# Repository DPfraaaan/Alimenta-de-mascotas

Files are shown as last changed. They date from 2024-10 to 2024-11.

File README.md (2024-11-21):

# Alimentador-de-mascotas

El proyecto consiste en un alimentador automático de mascotas que consta de un tanque de comida y un plato que incluye una balanza para medir el peso de la comida que hay en él. Este dispositivo rellenará automáticamente el plato cuando esté vacío.

### Funcionamiento Planteado: 
Con un botón se permitirá cambiar la frecuencia con la que se rellena el plato, con intervalos de 4 horas.
El alimentador contará con una pantalla que mostrará información como la cantidad de comida en gramos en el plato y el tiempo restante para el próximo rellenado, en caso de que el animal haya consumido toda la comida del plato actual. Por último, incluirá un sensor ultrasónico que medirá el nivel del tanque. Si está lleno, se encenderá un LED verde y si está bajo, un LED rojo. Cuando el nivel esté muy bajo, se activará un buzzer como alarma.

### Componentes:
* Sensor ultrasonido (Hc-sr04)
* Leds (Verde ;Rojo)
* Buzzer 
* Servo (sg-90)
* ESP-32
* Celda de carga (1kg) Hx711
* Pantalla LCD 16x2 I2C
* 1 Botón genéricO

#### Después se agrego:

* LDR

### Comunicación entre módulos y MCU
* i2c ( pantalla LCD, Servo, sensor de ultrasonido ) 
* 2 pines (Clock y Data), de forma serial muy similar a I2C (celda de carga)
* PWM (servomotor ( como tal no es un sistema ) )

## Diagrama de conexión



## Actualizaión:
Un botón fue eliminado debido a que no era relevante
* Se opto por solo un botón que permite cambiar los intervalos de relleno del plato de comida de a 4hs cada intervalo.

### Actualización V3:
Debido a distintos problemas.
* Se quitó celda de carga.
* Se agregó LDR.
* Se cambió el planteamento del funcionamiento.
  
¡¡Más info abajo del README!!

## Objetivos
* Lograr el funcionamiento propuesto en un inicio haciendo un dispositivo funcional y práctico

## Alcances
* No se completó en sí como se planteo inicialmente el proyecto, pero gracias a alternativas conseguimos un comedero automatico sin el uso de la báscula

## Problemas encontrados durante el proceso:
* Es importante tener en cuenta que el ESP trabaja con un nivel lógico de voltajes de 3,3 V, entonces la algunos de sensores u actuadores podrían no funcionar con los niveles lógicos del ESP por lo que lo ideal es implementar un logic level shifter de 5v <-- (nivel lógico de la mayoría de sensores implementados) a 3,3 V. (al final todos nuestros actuadores, sensores y LCD permitían su correcto funcionamiento con 3,3 V por lo que no se implementó).
* En nuestro caso la configuración de la resistencia de carga fue muy complicada y no pudimos conseguir el funcionamiento de esta; por esto es que decidimos hacer una versión del alimentador sin esta.

## Ideas para una futrura implementación
* Lograr el funcionamiento de la báscula para cumplir con la idea inicial. (o buscar alternativa a esta).
* Comunicación Wifi o bluethoot o un servidor para aumentar las funcionalidades
* Mejorar el diseño del dispositivo, (agregar más piezas impresas en 3D).

## Cómo funciona nuestra última versión sin báscula

Básicamente cuenta con un LDR que cuando detecta mucha luz (que esta de día), llena el recipiente de comida del animal, esto lo hace una vez en el día. Cuando es de noche o hay poca luz hablita la lectura del tanque, cuando está en niveles de comida adecuados prende un led verde, intermitente; cuando esta en niveles críticos prede un led rojo y un buzer intermitente. El botón se mantuvo este permite selecionar entre perro Grande (G), Mediano (M), Chico (C). Como no tenemos una báscula para medir los niveles de comida esto lo que hace es cambiar el tiempo de apertura del servo. Más tiempo, más comida (ej perro grande), menos tiempo menos comida (perro chico). La informacón de tipo de perro está mostrada en el LCD.

### ¡¡Información de hadware y software (LDR) se encuentran en el github!!

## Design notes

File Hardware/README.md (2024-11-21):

# Documentación
Aquí se encuentra información sobre los distintos componentes del proyecto, la función que cumplen, algunas características importantes de cada uno y el enlace a las hojas de datos (datasheets) de cada componente.
## Descripción:
### ESP-32


 El ESP-32 es un microcontrolador potente y versátil que cuenta con conectividad Wi-Fi y Bluetooth. Es ideal para proyectos de Internet de las Cosas (IoT) y ofrece múltiples pines de entrada/salida, así como capacidades de procesamiento para ejecutar diversas aplicaciones.
 
------------------

### Sensor Ultrasonido (HC-SR04)
Descripción de la imagen

El HC-SR04 es un sensor de distancia que utiliza ondas ultrasónicas para medir la distancia a un objeto. Emite un pulso de sonido a 40 kHz y mide el tiempo que tarda en regresar el eco. Es útil en aplicaciones como la medición de distancias y la detección de obstáculos.

------------------

### LEDs (Verde, Amarillo, Rojo)
Descripción de la imagen

Los LEDs (diodos emisores de luz) son componentes electrónicos que emiten luz cuando se les aplica corriente. En este caso, los LEDs de colores (verde, amarillo y rojo) se pueden usar para indicar estados diferentes en un sistema, como el funcionamiento normal (verde), advertencias (amarillo) o errores (rojo).

------------------

### Buzzer
Descripción de la imagen

El buzzer es un dispositivo que produce sonido al recibir una señal eléctrica. Puede ser un buzzer pasivo (requiere una señal de audio) o activo (produce un tono fijo). Se utiliza en alarmas, notificaciones y sistemas de alerta.

------------------

### Servo (SG-90)
Descripción de la imagen

El SG-90 es un servomotor de bajo costo que permite un control preciso de la posición angular. Tiene un rango de movimiento de aproximadamente 180 grados y se utiliza comúnmente en aplicaciones de robótica y automatización, como el control de brazos robóticos o mecanismos de dirección.

------------------

### Celda de Carga (1 kg) con HX711
Descripción de la imagen
Descripción de la imagen

La celda de carga es un sensor que mide el peso aplicando una fuerza. En este caso, tiene una capacidad de 1 kg. El HX711 es un amplificador de señal diseñado para leer la salida de la celda de carga, permitiendo medir con precisión el peso en aplicaciones de pesaje y balanzas.

------------------

### Pantalla LCD 16x2 I2C
Descripción de la imagen

Esta pantalla LCD tiene 16 columnas y 2 filas, y utiliza la interfaz I2C para comunicarse con otros dispositivos, lo que simplifica el cableado y la programación. Es ideal para mostrar información, como datos del sensor o mensajes al usuario, en proyectos electrónicos.

------------------

## Si usa LDR
### LDR
images

LDR de 40 KOHM
* Si se desea se puede confiugurar un PULL UP desede las mismas configuraciones del ESP.
* En este caso se utilizo un PULL UP físico.

### Diagrama Pull UP (RPU 10 KOHM)

Captura de pantalla 2024-11-21 201753

## Aviso

#### ¡Se pueden usar los pines que quedan libres al no usar la báscula, quedando 1 sin uso!
EJ:
  
Captura de pantalla 2024-11-21 202111

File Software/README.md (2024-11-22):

# Bibliografía

### Servo 
https://www.youtube.com/watch?v=jJQG936B6uM 

### Hx-711 ( celda de carga )  
https://github.com/akshayvernekar/HX711_IDF/tree/master

## Diagrama de flujo bascula

```mermaid
flowchart TD
    %% Main initialization
    A[Start] --> B[Initialize I2C & LCD]
    B --> C[General Config\n- GPIO Setup\n- Servo PWM Setup]
    C --> D[Configure Hardware Timers\n- Ultrasonic Timer\n- Servo Timers]
    D --> E[Initialize Ultrasonic Sensor]
    
    %% Task Creation
    E --> F[Create FreeRTOS Tasks]
    
    %% Core 0 Tasks
    F --> G[Core 0]
    G --> H[Button Task]
    
    %% Core 1 Tasks
    F --> I[Core 1]
    I --> J[LCD Update Task]
    
    %% Monitor Task (Any Core)
    F --> K[Any Core]
    K --> L[Monitor Task]
    
    %% Button Task Flow
    H --> M{Button\nPressed?}
    M -- Yes --> N[Increment Timer\nby 2 Hours]
    N --> O{Hours >= 24?}
    O -- Yes --> P[Reset Hours to 0]
    O -- No --> M
    P --> M
    
    %% Timer Callback Flow
    Q[Hardware Timer\nCallback] --> R[Increment Minutes]
    R --> S{Minutes >=\nSet Hours?}
    S -- Yes --> T[Check Distance]
    
    %% Distance and Weight Check
    T --> U{Distance\n> 100cm?}
    U -- Yes --> V[Red LED Blink\nShow 'Falta comida']
    U -- No --> W{50cm < Distance\n<= 100cm?}
    W -- Yes --> X[Green LED On\nShow 'Comida ok']
    W -- No --> Y[LEDs Off]
    
    %% Weight Check and Servo Control
    V & X & Y --> Z[Check Weight]
    Z --> AA{Weight\n> 1.5kg?}
    AA -- Yes --> AB[Show 'Hay comida']
    AA -- No --> AC[Move Servo 90°]
    AC --> AD[Wait 500ms]
    AD --> AE[Move Servo 0°]
    
    %% LCD Update Task Flow
    J --> AF{Update\nNeeded?}
    AF -- Yes --> AG[Clear LCD]
    AG --> AH[Show Status]
    AH --> AI[Show Remaining Time]
    AI --> AJ[Reset Update Flag]
    AJ --> AF
    AF -- No --> J
    
    %% Monitor Task Flow
    L --> AK[Check Stack Usage]
    AK --> AL[Print Stack Info]
    AL --> L
    
    %% Styling
    classDef core0 fill:#FFB6C1,stroke:#333,stroke-width:2px
    classDef core1 fill:#90EE90,stroke:#333,stroke-width:2px
    classDef anyCore fill:#87CEEB,stroke:#333,stroke-width:2px
    classDef hardware fill:#FFD700,stroke:#333,stroke-width:2px
    classDef init fill:#DDA0DD,stroke:#333,stroke-width:2px
    
    class A,B,C,D,E,F init
    class G,H,M,N,O,P core0
    class I,J,AF,AG,AH,AI,AJ core1
    class K,L,AK,AL anyCore
    class Q,R,S,T,U,V,W,X,Y,Z,AA,AB,AC,AD,AE hardware
```

## Diagrama de flujo LDR
```mermaid
flowchart TD
    %% Style definitions
    classDef start fill:#4CAF50,stroke:#45a049,color:white
    classDef init fill:#2196F3,stroke:#1976D2,color:white
    classDef process fill:#90CAF9,stroke:#64B5F6,color:black
    classDef decision fill:#FFA726,stroke:#FB8C00,color:black
    classDef alert fill:#EF5350,stroke:#E53935,color:white
    classDef success fill:#66BB6A,stroke:#4CAF50,color:white
    classDef servo fill:#AB47BC,stroke:#8E24AA,color:white
    classDef return fill:#78909C,stroke:#607D8B,color:white

    A[Start] --> B[Initialize Hardware]
    B --> C[Display 'Alimentador' on LCD]
    C --> D{Main}
    
    D --> E[Read Button State]
    E --> F{Button Pressed?}
    F -->|Yes| G[Increment Pet Size]
    G --> H[Update LCD with Size]
    H --> I{5 seconds passed?}
    I -->|Yes| J[Display 'seleccionado']
    I -->|No| D
    F -->|No| K[Check LDR Value]
    
    K --> L{Is it Night?<br/>LDR > threshold}
    L -->|Yes| M[Check Food Level<br/>with Ultrasonic]
    M --> N{Distance > Max_cm?}
    N -->|Yes| O[Blink Red LED<br/>Sound Buzzer]
    N -->|No| P{Min_cm < Distance < Max_cm?}
    P -->|Yes| Q[Blink Green LED]
    
    L -->|No| R{LDR < 600 AND<br/>servobreaker true?}
    R -->|Yes| S[Open Servo 90°]
    S --> T{Check Pet Size}
    T -->|Large| U[Wait 2s]
    T -->|Medium| V[Wait 1s]
    T -->|Small| W[Wait 0.5s]
    U --> X[Close Servo 0°]
    V --> X
    W --> X
    X --> Y[Set servobreaker false]
    
    O --> D
    Q --> D
    Y --> D
    P -->|No| D
    R -->|No| D

    %% Apply styles
    class A start
    class B,C init
    class E,G,H,J,K,M process
    class F,I,L,N,P,R,T decision
    class O alert
    class Q success
    class S,U,V,W,X,Y servo
    class D return
```

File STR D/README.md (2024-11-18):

## Programa Utilizado
Se utilizo Tinkercad como programa de diseño en 3D

Logo-tinkercad-wordmark svg

## ÚTIL
Ademas de las piezas diseñadas en 3D para el tanque se utilizó un bidón de 5 lts, para el alimentador se utlizó un bowl de comida de gato universal

unnamed

(En la imágen se puede observar una boquilla que se diseñó para ayudar al servo en su tarea como valvula de apertura y cierre)

## Metodos de unión
* Cinta doble faz
* Silicona

## Case; placa y componentes principales.

Captura

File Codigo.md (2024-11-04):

## Codigo para el esp32

## bibliografia
https://www.youtube.com/watch?v=jJQG936B6uM
https://www.youtube.com/watch?v=OKbQIeM_1Bs
https://github.com/hardrive9000/PetFeeder/blob/master/Code/main/main.c

https://github.com/UncleRus/esp-idf-lib/tree/master/docs  (este para hx711)

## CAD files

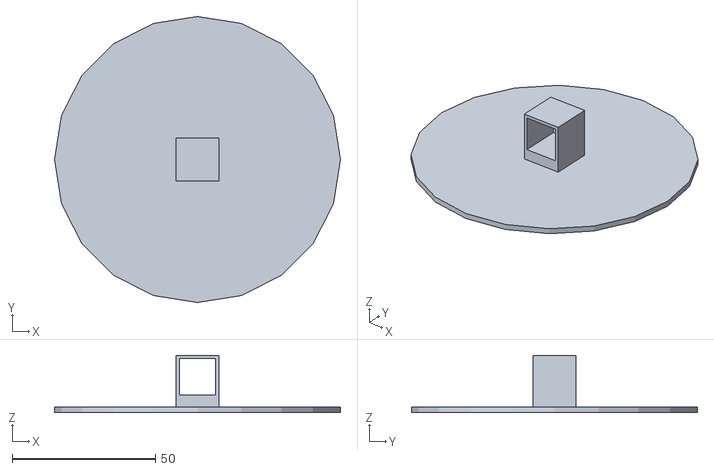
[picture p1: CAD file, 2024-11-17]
STR D/STLS/Soporte bowl.stl
100.0 x 100.0 x 20.0

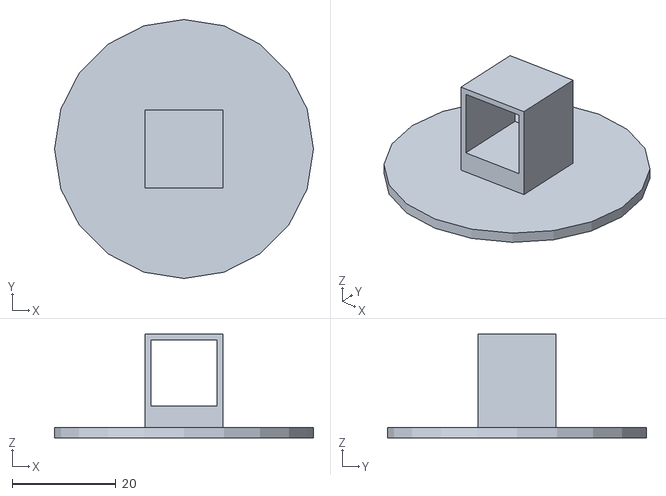
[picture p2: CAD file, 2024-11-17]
STR D/STLS/Soporte sensor Bowl.stl
50.0 x 50.0 x 20.0

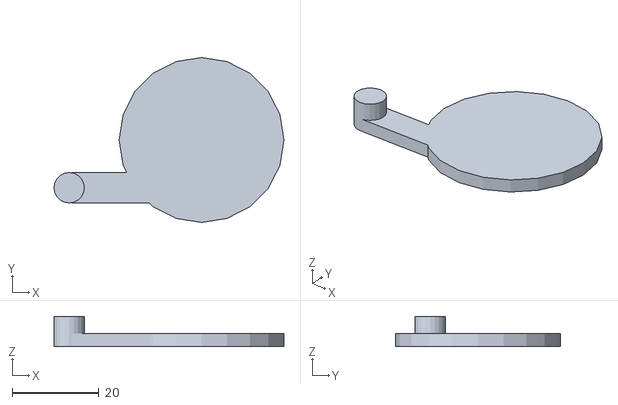
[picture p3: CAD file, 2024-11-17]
STR D/STLS/Brazo servo.stl
53.0 x 38.0 x 7.00

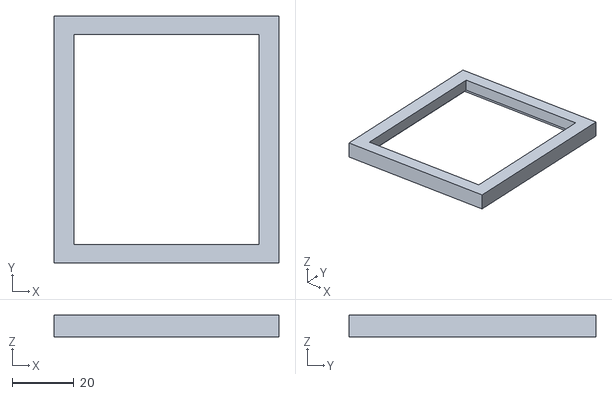
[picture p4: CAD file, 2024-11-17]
STR D/STLS/Separador BOX y BOX2.stl
73.0 x 80.0 x 7.00

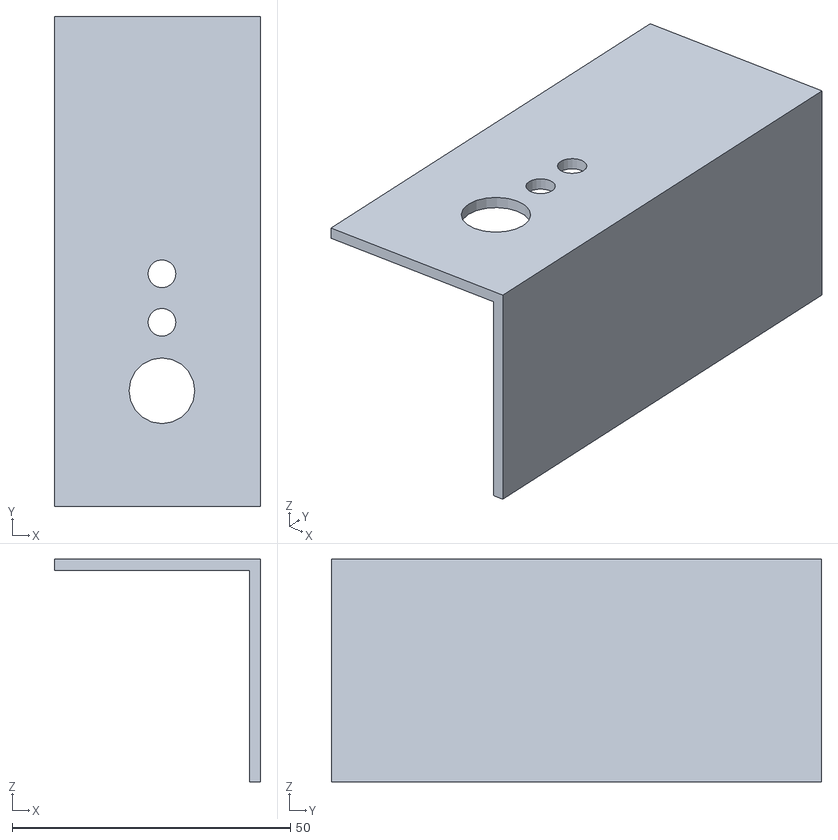
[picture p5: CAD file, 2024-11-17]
STR D/STLS/Porta LED y BUZZer.stl
37.0 x 88.0 x 40.0

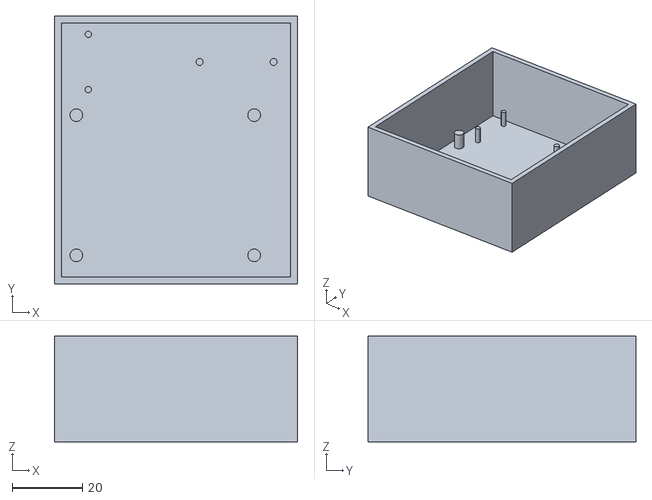
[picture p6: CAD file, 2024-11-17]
STR D/STLS/BOX principal ESP.stl
69.0 x 76.0 x 30.0

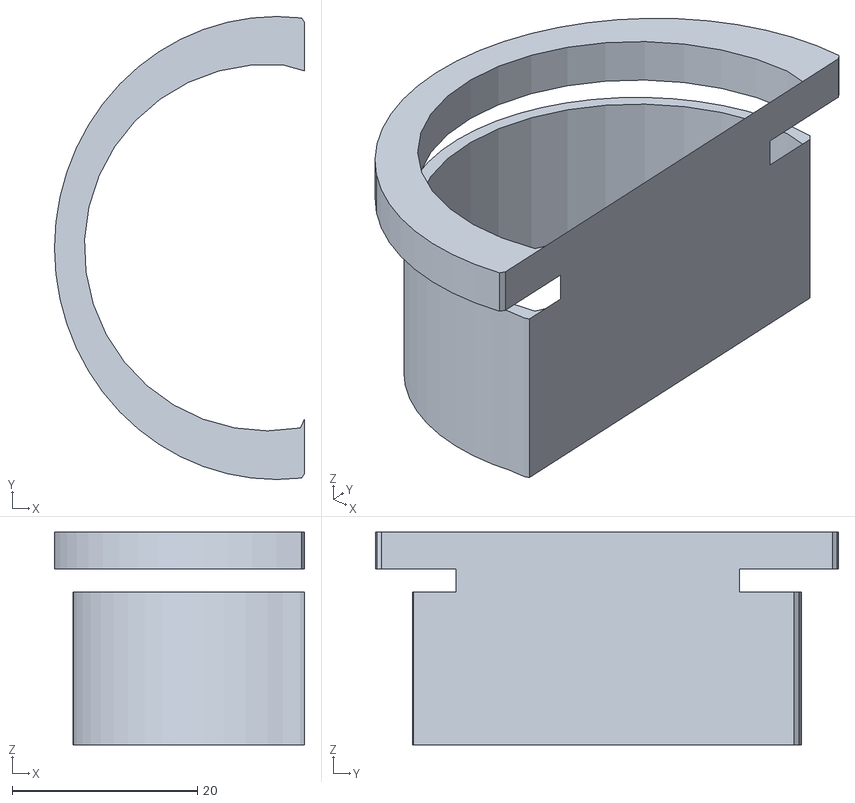
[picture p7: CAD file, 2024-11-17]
STR D/STLS/Boquilla tanque.stl
27.0 x 50.0 x 23.0

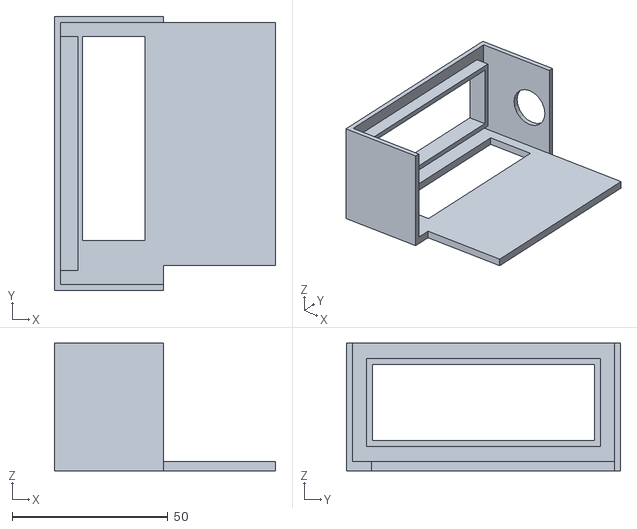
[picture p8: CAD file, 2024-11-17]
STR D/STLS/BOX 2 PANTALLA.stl
71.0 x 88.0 x 41.0

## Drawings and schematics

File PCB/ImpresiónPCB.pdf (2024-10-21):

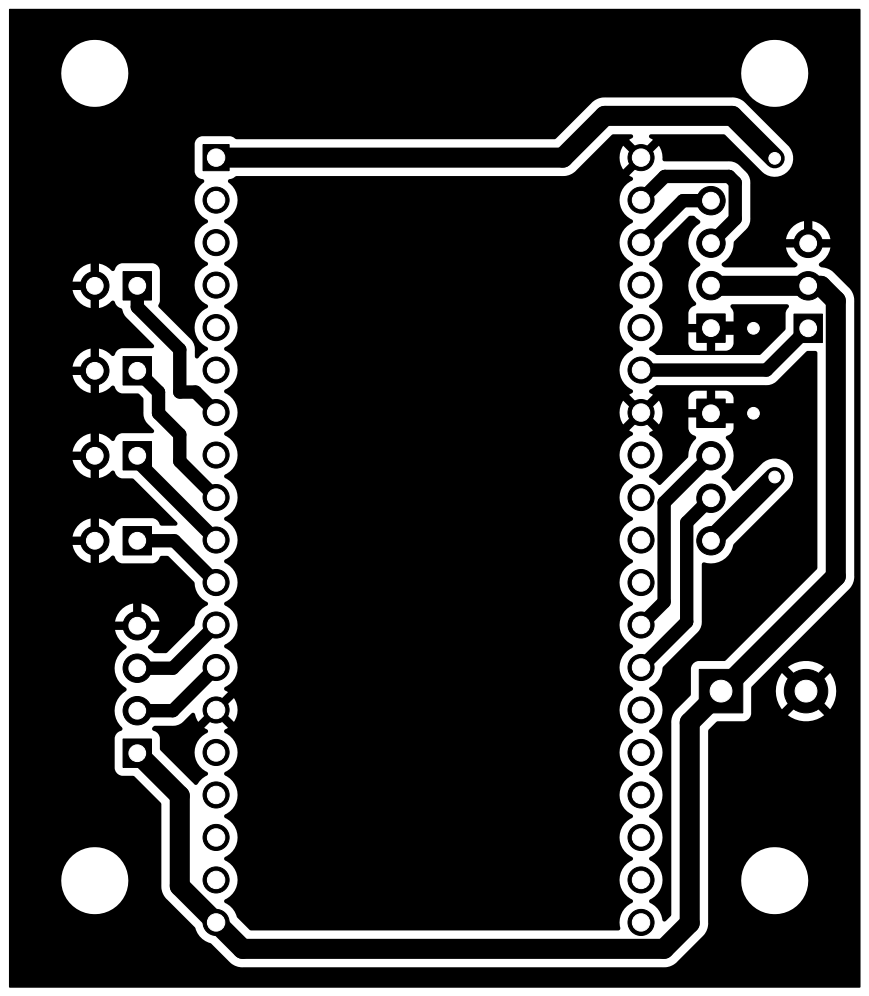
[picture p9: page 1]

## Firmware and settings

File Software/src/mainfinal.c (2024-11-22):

#include <stdio.h>
#include "freertos/FreeRTOS.h"
#include "freertos/task.h"
#include "unistd.h"
#include "rom/ets_sys.h"
#include "math.h"

#include "esp_timer.h"
#include "esp_log.h"
#include "esp_err.h"

#include "driver/gpio.h"
#include "driver/adc.h"
#include "driver/ledc.h"
#include "driver/i2c.h"

#include "ultrasonic.h"
#include "ultrasonic.c"
#include "brasuca.h"


// Definir pines y variables
#define RED_LED_PIN GPIO_NUM_26
#define GREEN_LED_PIN GPIO_NUM_32
#define BUZZER_PIN GPIO_NUM_25

uint32_t duty;
#define servopin 4

#define BUTTON_PIN GPIO_NUM_13
#define MAX_ANIMAL 2
int TAMANO_ANIMAL = 0;
uint32_t presion_boton = 0;

//ultrasonido
#define PIN_ECHO GPIO_NUM_14
#define PIN_TRIGGER GPIO_NUM_12
#define MAX_DISTANCE_CM 400 //esto para config
#define MAX_CM 17
#define MIN_CM 4
uint32_t distancia;

// Variables de tiempo
unsigned long prevMillisUltrasonido = 0;
unsigned long prevMillisServo = 0;
unsigned long intervalUltrasonido = 60000; // 1 minuto
unsigned long intervalServo = 500; // 500 ms

ultrasonic_sensor_t sensor; // Variable global


//inicio LDR -----------------------------
int rawLDR;
bool servobreaker = true;

#define ADC_1 1
#define ADC_2 2

typedef struct {
  uint8_t adc_device;
  uint8_t adc_channel;
  float k1;
  float k2;
} ldr_handle_t;

ldr_handle_t ldr; // Declaración global

float ldr_get_illuminance(ldr_handle_t * ldr) {
  if (ldr->adc_device == ADC_2) {
    int buffer;
    adc2_get_raw(ldr->adc_channel, ADC_WIDTH_BIT_12, &buffer);
    return ldr->k1 + ldr->k2 * log((4096.0 / buffer) - 1);
  }

  else {
    return ldr->k1 + ldr->k2 * log((4096.0 / adc1_get_raw(ldr->adc_channel)) - 1);
  }
}

#define THRESHOLD 3600 // valor max del rawLDR

// rawLDR = (ldr_get_illuminance(&ldr)/100)*4096-1

// fin de LDR--------------------------------------

// inicio i2c--------------------------------------

lcd_i2c_handle_t display;

void i2c_init() 
{
  i2c_config_t i2c_config = {
      .mode = I2C_MODE_MASTER,
      .sda_io_num = 22,
      .sda_pullup_en = 1,
      .scl_io_num = 21,
      .scl_pullup_en = 1,
      .master.clk_speed = 100000,
    };

    i2c_param_config(I2C_NUM_1, &i2c_config);

    i2c_driver_install(I2C_NUM_1, I2C_MODE_MASTER, 0, 0, 0);
}

bool actualizacion_lcd_necesaria = false;

void lcd_i2c_clear(lcd_i2c_handle_t * lcd) {
  lcd_i2c_write(lcd, 0, CLEAR_DISPLAY); // Limpia la pantalla
  vTaskDelay(10 / portTICK_PERIOD_MS);   // Espera para que el LCD procese el comando
}
// fin i2c-----------------------------------------

void servoconfig()
{
  ledc_timer_config_t timer = {
    .speed_mode = LEDC_LOW_SPEED_MODE,
    .duty_resolution = LEDC_TIMER_13_BIT,
    .timer_num = LEDC_TIMER_0,
    .freq_hz = 50,
    .clk_cfg = LEDC_AUTO_CLK
  };
  ledc_timer_config(&timer);

  ledc_channel_config_t channel = {
    .speed_mode = LEDC_LOW_SPEED_MODE,
    .channel = LEDC_CHANNEL_0,
    .timer_sel = LEDC_TIMER_0,
    .intr_type = LEDC_INTR_DISABLE,
    .gpio_num = servopin,
    .duty = 0,
    .hpoint = 0
  };
  ledc_channel_config(&channel);
}

void ultrasonico_init() 
{
    sensor.trigger_pin = PIN_TRIGGER;
    sensor.echo_pin = PIN_ECHO;
    ultrasonic_init(&sensor);
}

uint32_t medir_dis()
{
  uint32_t distance;
  esp_err_t res = ultrasonic_measure_cm(&sensor, MAX_DISTANCE_CM, &distance);
  return distance;  // Retorna la distancia medida
}

void generalconfig()
{
  esp_rom_gpio_pad_select_gpio(RED_LED_PIN);
  gpio_set_direction(RED_LED_PIN, GPIO_MODE_OUTPUT);

  esp_rom_gpio_pad_select_gpio(GREEN_LED_PIN);
  gpio_set_direction(GREEN_LED_PIN, GPIO_MODE_OUTPUT);

  esp_rom_gpio_pad_select_gpio(BUZZER_PIN);
  gpio_set_direction(BUZZER_PIN, GPIO_MODE_OUTPUT);

  esp_rom_gpio_pad_select_gpio(BUTTON_PIN);
  gpio_set_direction(BUTTON_PIN, GPIO_MODE_INPUT);
  gpio_set_pull_mode(BUTTON_PIN, GPIO_PULLUP_ONLY);
  // gpio_pullup_en(BUTTON_PIN);  // Habilitar pull-up interno
  
}


void boton() 
{
    if (gpio_get_level(BUTTON_PIN) == 0) {
        presion_boton = esp_timer_get_time();
        TAMANO_ANIMAL += 1;
        if (TAMANO_ANIMAL > MAX_ANIMAL) {
            TAMANO_ANIMAL = 0;
        }
        // lcd_clear();
        lcd_i2c_clear(&display);
        lcd_i2c_cursor_set(&display, 1, 0); 
        lcd_i2c_print(&display, "Tm: "); 
        lcd_i2c_cursor_set(&display, 1, 3);
        if (TAMANO_ANIMAL == 1) {
            lcd_i2c_print(&display, "G");
        } else if (TAMANO_ANIMAL == 2) {
            lcd_i2c_print(&display, "M");
        } else {
            lcd_i2c_print(&display, "C");
        }
        vTaskDelay(100 / portTICK_PERIOD_MS);
    }
    // Verificar si pasaron 5 segundos sin presionar el botón
    if (presion_boton > 0 && (esp_timer_get_time() - presion_boton) >= 5000000) {
        presion_boton = 0; // Resetear tiempo de presión
        lcd_i2c_cursor_set(&display, 1, 3);  
        lcd_i2c_print(&display, "seleccionado"); 
    }
    vTaskDelay(100 / portTICK_PERIOD_MS);
}

void porongus() 
{
  // Leer el valor del LDR
  rawLDR = (ldr_get_illuminance(&ldr)/100)*4096-1;
  if (rawLDR > THRESHOLD) { // No hay luz (si es de noche)
    // Lo siguiente es para comida de tanque
    uint32_t distancia = medir_dis();
    servobreaker = true;
    if (distancia > MAX_CM) {
        gpio_set_level(RED_LED_PIN, 1);
        gpio_set_level(BUZZER_PIN, 1);
        vTaskDelay(250 / portTICK_PERIOD_MS);
        gpio_set_level(RED_LED_PIN, 0);
        gpio_set_level(BUZZER_PIN, 0);
        vTaskDelay(250 / portTICK_PERIOD_MS);
    } else if (distancia > MIN_CM && distancia < MAX_CM) {
        gpio_set_level(GREEN_LED_PIN, 1);
        vTaskDelay(500 / portTICK_PERIOD_MS);
        gpio_set_level(GREEN_LED_PIN, 0);
        vTaskDelay(500 / portTICK_PERIOD_MS);
      }
  } else if (rawLDR < 600 && servobreaker == true) { // De día
    duty = 600; // 90 grados
    ledc_set_duty(LEDC_LOW_SPEED_MODE, LEDC_CHANNEL_0, duty);
    ledc_update_duty(LEDC_LOW_SPEED_MODE, LEDC_CHANNEL_0);

    if (TAMANO_ANIMAL == 1) {
        vTaskDelay(2000 / portTICK_PERIOD_MS); // Grande
    } else if (TAMANO_ANIMAL == 2) {
        vTaskDelay(1000 / portTICK_PERIOD_MS); // Mediano
    } else {
        vTaskDelay(500 / portTICK_PERIOD_MS); // Chico
    }
    duty = 200; // 0 grados
    ledc_set_duty(LEDC_LOW_SPEED_MODE, LEDC_CHANNEL_0, duty);
    ledc_update_duty(LEDC_LOW_SPEED_MODE, LEDC_CHANNEL_0);

    if (TAMANO_ANIMAL == 1) {
        vTaskDelay(2000 / portTICK_PERIOD_MS); // Grande
    } else if (TAMANO_ANIMAL == 2) {
        vTaskDelay(1000 / portTICK_PERIOD_MS); // Mediano
    } else {
        vTaskDelay(500 / portTICK_PERIOD_MS); // Chico
    }
    servobreaker = false;
  }
}

void app_main(void) 
{
  adc1_config_width(ADC_WIDTH_BIT_12);
  adc1_config_channel_atten(ADC1_CHANNEL_7,  ADC_ATTEN_DB_11);

  ldr.adc_device = ADC_1;
  ldr.adc_channel = ADC1_CHANNEL_7;
  ldr.k1 = 49.95095;
  ldr.k2 = 10.34034;
  
  //inicio config
  servoconfig();
  ultrasonico_init();
  generalconfig();

  i2c_init();
  display = (lcd_i2c_handle_t) {
    .address = 0x27,
    .num = I2C_NUM_1,
    .backlight = 1,
    .size = DISPLAY_16X02
  };
  lcd_i2c_init(&display);

  lcd_i2c_cursor_set(&display, 1, 5);  // Mover el cursor a la fila 1, columna 3
  lcd_i2c_print(&display, "Alimentador");  // Escribir en la pantalla

  while (1) 
  {
    boton();
    porongus();
    vTaskDelay(100 / portTICK_PERIOD_MS);
  }
}

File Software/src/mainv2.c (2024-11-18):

// Basicos 
#include <stdio.h> 
#include "freertos/FreeRTOS.h"
#include "freertos/task.h"
#include "nvs_flash.h"
#include "esp_system.h"
#include "esp_event.h"
#include "esp_log.h"
#include "esp_err.h"
#include "esp_timer.h"
//configMINIMAL_STACK_SIZE = 1024 y esto es como para una tarea de LED BLINK nada más, en perspectiva

// Drivers & librerías
#include "driver/gpio.h" 
#include "driver/ledc.h"
#include "driver/i2c.h" 
#include "../lib/i2c-lcd.h"
#include "../lib/ultrasonido.h"

// General definiciones-----------------------------------------------------------------------
#define BUTTON_PIN 8
#define BUZZER_PIN 10
#define REDLED_PIN 11
#define GREENLED_PIN 12
#define TRIGGER_GPIO 5
#define ECHO_GPIO 18
#define SERVO_PIN 2

// Referido a sensor ultrasonico & LCD
static const int DISTANCIA_UMBRAL_ALTO = 100;  // Umbral alto (cm)
static const int DISTANCIA_UMBRAL_BAJO = 50;   // Umbral bajo (cm)
static const int MAX_HORAS = 24;
static const int MINUTOS_POR_HORA = 60;
int HORAS_ESPERA_ULTRASONIDO; // variable a modificar
static bool es_ultrasonido_activado = false;

static uint32_t presion_boton = 0;
static uint32_t minutos_transcurridos = 0;

static bool actualizacion_lcd_necesaria = false;
static char status_message[32];  // Mensaje a mostrar en el LCD
static int remaining_time = 0;   // Tiempo restante para mostrar en el LCD

esp_timer_handle_t temporizador_ultrasonido;
esp_timer_handle_t temporizador_servo_90;
esp_timer_handle_t temporizador_servo_0;


// i2c definiciones--------------------------------------------------------------------------- 
static const char *TAG_LCD = "LCD"; 
#define I2C_MASTER_SCL_IO GPIO_NUM_22 //GPIO number used for I2C master clock  
#define I2C_MASTER_SDA_IO GPIO_NUM_21 // GPIO number used for I2C master data  
#define I2C_MASTER_NUM 0 // I2C master i2c port number, the number of i2c peripheral interfaces available will depend on the chip 
#define I2C_MASTER_FREQ_HZ 400000 // I2C master clock frequency 
#define I2C_MASTER_TX_BUF_DISABLE 0 // I2C master doesn't need buffer 
#define I2C_MASTER_RX_BUF_DISABLE 0 // I2C master doesn't need buffer 
#define I2C_MASTER_TIMEOUT_MS 1000 
char buffer[10]; 
float num = 12.34;
esp_err_t esp_err; 
#define I2C_NUM I2C_NUM_0 

// hx711 definiciones-------------------------------------------------------------------------
#define AVG_SAMPLES   10
#define GPIO_PD_SCK   GPIO_NUM_15
#define GPIO_DOUT   GPIO_NUM_16
#define GAIN 128
unsigned long Pesocomida = 0;
float pesoMAX = 1.5; //suponemos kg
static const char* TAG_HX711 = "HX711";

static esp_err_t i2c_master_init(void) // Configuración del lcd i2c---------------------------
{ 
    
    int i2c_master_port = I2C_MASTER_NUM;

    i2c_config_t conf = {
        .mode = I2C_MODE_MASTER,
        .sda_io_num = I2C_MASTER_SDA_IO,
        .scl_io_num = I2C_MASTER_SCL_IO,
        .sda_pullup_en = GPIO_PULLUP_ENABLE,
        .scl_pullup_en = GPIO_PULLUP_ENABLE,
        .master.clk_speed = I2C_MASTER_FREQ_HZ,
    };

    i2c_param_config(i2c_master_port, &conf);
    return i2c_driver_install(i2c_master_port, conf.mode, I2C_MASTER_RX_BUF_DISABLE, I2C_MASTER_TX_BUF_DISABLE, 0);
}

static void read_weight(void) // Configuración del HX711 -------------------------------------
{
    HX711_init(GPIO_DOUT, GPIO_PD_SCK, GAIN); 
    HX711_tare();

    unsigned long weight = HX711_get_units(AVG_SAMPLES);
    ESP_LOGI(TAG_HX711, "******* weight = %ld *********\n", weight);
    Pesocomida = weight;  // Guardar el peso en la variable global
}

static void generalconfig()
{
    esp_rom_gpio_pad_select_gpio(BUTTON_PIN);
    esp_rom_gpio_pad_select_gpio(BUZZER_PIN);
    esp_rom_gpio_pad_select_gpio(REDLED_PIN);
    esp_rom_gpio_pad_select_gpio(GREENLED_PIN);
    gpio_set_direction(BUTTON_PIN, GPIO_MODE_INPUT);
    gpio_set_direction(BUZZER_PIN, GPIO_MODE_OUTPUT);
    gpio_set_direction(REDLED_PIN, GPIO_MODE_OUTPUT);
    gpio_set_direction(GREENLED_PIN, GPIO_MODE_OUTPUT);

    // Servo config
    ledc_timer_config_t timer = { 
        .speed_mode = LEDC_LOW_SPEED_MODE, 
        .duty_resolution = LEDC_TIMER_8_BIT, // Resolución de 8 bits (0-255) 
        .timer_num = LEDC_TIMER_0, //eleccion del timer 
        .freq_hz = 50, // Frecuencia de 50 Hz para control de servomotor 
        .clk_cfg = LEDC_AUTO_CLK 
        }; 
        ledc_timer_config(&timer);

    // Configuración del canal PWM
    ledc_channel_config_t channel = {
        .gpio_num = SERVO_PIN,  // GPIO donde está conectado el servomotor
        .speed_mode = LEDC_LOW_SPEED_MODE,
        .channel = LEDC_CHANNEL_0,
        .timer_sel = LEDC_TIMER_0,
        .duty = 0,  // Ciclo de trabajo inicial
        .hpoint = 0
        };
        ledc_channel_config(&channel);
        // ledc_fade_func_install(0); // Instalamos la función de desvanecimiento (fade) para suavizar el control de velocidad
}

static void boton()
{
 while (true)
    {
        if (gpio_get_level(BUTTON_PIN) == 1) {
            presion_boton = xTaskGetTickCount() * portTICK_PERIOD_MS; // Guardar el tiempo de presion del botón

            // Incrementar horas del temporizador
            HORAS_ESPERA_ULTRASONIDO += 2;
            if (HORAS_ESPERA_ULTRASONIDO >= MAX_HORAS) {
                HORAS_ESPERA_ULTRASONIDO = 0;
            }
            ESP_LOGI("TEMPORIZADOR", "Horas del temporizador: %d", HORAS_ESPERA_ULTRASONIDO);

            vTaskDelay(100 / portTICK_PERIOD_MS); // Pequeño delay para evitar bouncing
        }

        // Verificar si pasaron 5 segundos sin presionar el botón
        if (presion_boton > 0 && (xTaskGetTickCount() * portTICK_PERIOD_MS - presion_boton) >= 5000) {
            presion_boton = 0; // Resetear tiempo de presion
            //iniciar temporizador agregar
        }

        vTaskDelay(100 / portTICK_PERIOD_MS); // Delay para evitar alta carga de CPU
    }
}

static void toggle_red_led()
{
    gpio_set_level(REDLED_PIN, 1);
    vTaskDelay(pdMS_TO_TICKS(500));  // Encender por 500ms
    gpio_set_level(REDLED_PIN, 0);
    vTaskDelay(pdMS_TO_TICKS(500));  // Apagar por 500ms
}

static void turn_on_green_led()
{
    gpio_set_level(GREENLED_PIN, 1);  // Encender el LED verde
}

static void turn_off_green_led()
{
    gpio_set_level(GREENLED_PIN, 0);  // Apagar el LED verde
}
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

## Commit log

2024-10-16 Update and rename Brunch to PCB
2024-10-21 Add files via upload
    Trazado para imprimirlo
2024-11-04 Para LCD 16x2 con i2c
    es un ejemplo de codigo sobre el cual vamos a trabajar
2024-11-13 Create Codigo Alpha v0.1.md
    es un menjunje de codigo hasta ahora
2024-11-18 Add files via upload
    Headers para el código
2024-11-18 Update README.md
    Ahora hay dos versiones del código para su observación
